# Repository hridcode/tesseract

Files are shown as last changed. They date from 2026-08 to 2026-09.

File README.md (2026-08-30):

# Tesseract

Tesseract is a retro-style MP3 player with audio output to speakers and headphones, an LCD display, and battery charging for on-the-go listening. I made this because I wanted to have a dedicated device to run a library of my favorite music in a simplistic way, as a sort of action against streaming services.

## Features

- 32-bit 48kHz stereo output to speakers and headphones
- microSD card file loading (up to 32GB)
- 2.0" LCD display (ST7789)
- Battery charging with power path
- Album and artist shuffling modes
- Genre tags

## Pictures

|Schematic|PCB|Case|
|---|---|---|
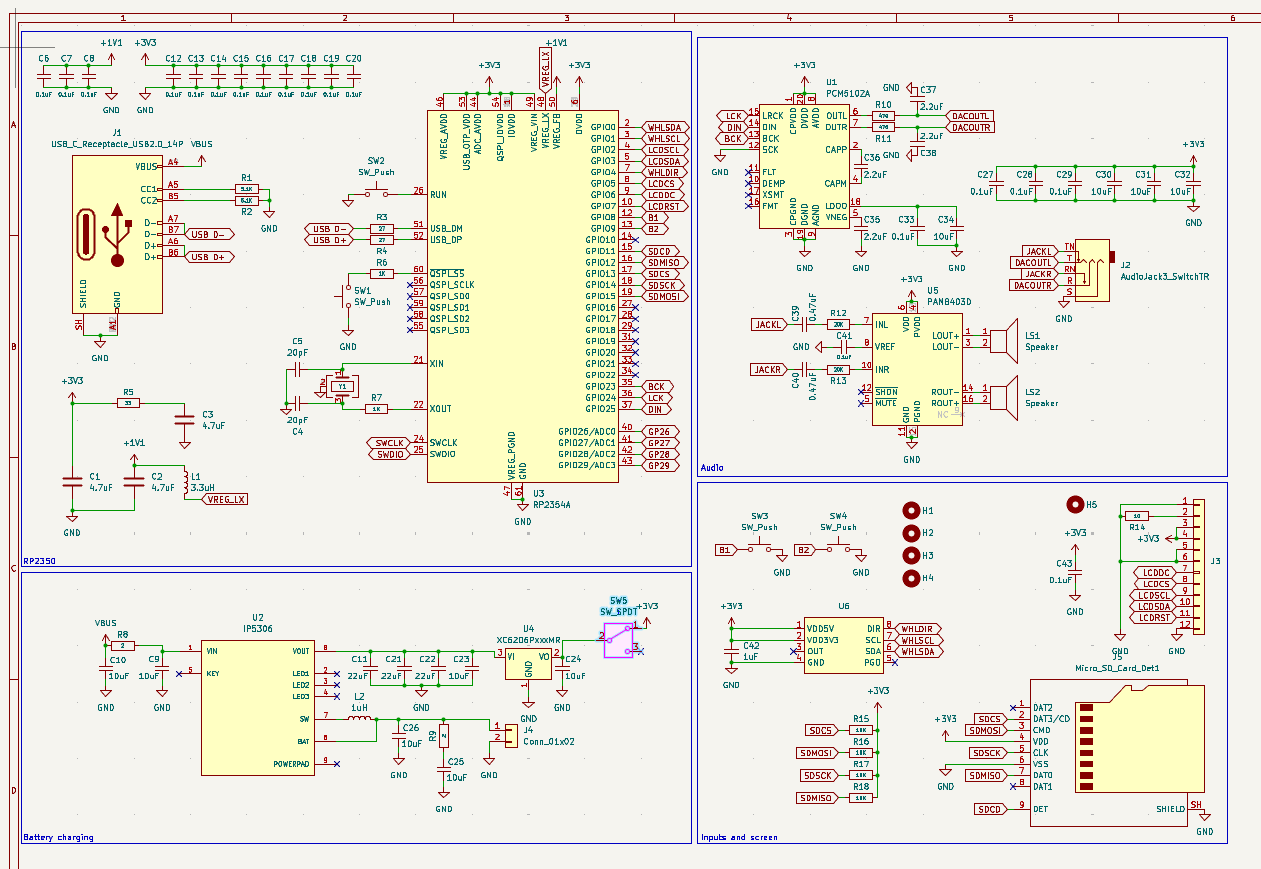
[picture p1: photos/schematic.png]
Schematic
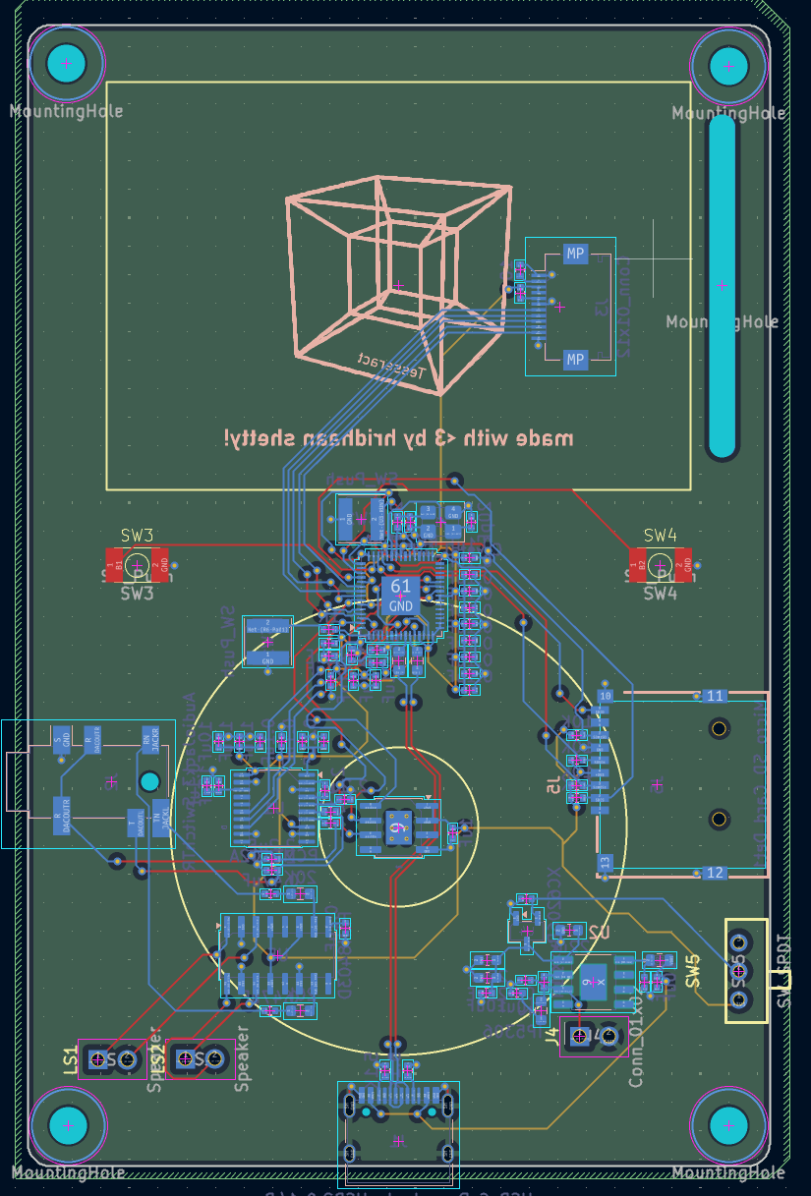
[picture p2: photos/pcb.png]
PCB
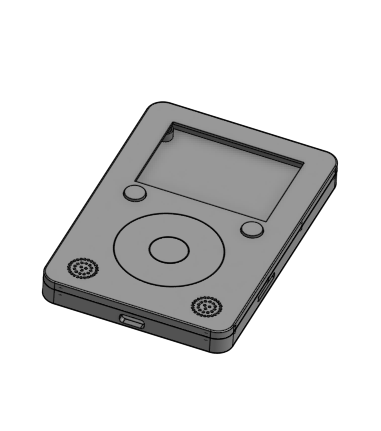
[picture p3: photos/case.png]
Case
||||

## BOM

|Part|Quantity|Cost|Link|
|---|---|---|---|
|0402 4.7uF capacitor|3|$0.070|[LCSC](https://www.lcsc.com/product-detail/C23733.html)|
|0402 10uF capacitor|10|$0.258|[LCSC](https://www.lcsc.com/product-detail/C15525.html)|
|0603 22uF capacitor|3|$0.094|[LCSC](https://www.lcsc.com/product-detail/C59461.html)|
|0402 0.1uF capacitor|18|$0.099|[LCSC](https://www.lcsc.com/product-detail/C1525.html)|
|0402 2.2uF capacitor|4|$0.026|[LCSC](https://www.lcsc.com/product-detail/C12530.html)|
|0402 0.47uF capacitor|2|$0.028|[LCSC](https://www.lcsc.com/product-detail/C47339.html)|
|0402 20pF capacitor|2|$0.016|[LCSC](https://www.lcsc.com/product-detail/C1554.html)|
|0402 1uF capacitor|1|$0.012|[LCSC](https://www.lcsc.com/product-detail/C52923.html)|
|microSD card receptacle|1|$0.061|[LCSC](https://www.lcsc.com/product-detail/C7529389.html)|
|0402 3.3uH inductor|1|$0.076|[LCSC](https://www.lcsc.com/product-detail/C48946153.html)|
|0402 1uH inductor|1|$0.035|[LCSC](https://www.lcsc.com/product-detail/C22400378.html)|
|0402 5.1KΩ resistor|2|$0.005|[LCSC](https://www.lcsc.com/product-detail/C25905.html)|
|0402 470Ω resistor|2|$0.010|[LCSC](https://www.lcsc.com/product-detail/C25117.html)|
|0603 20KΩ resistor|2|$0.008|[LCSC](https://www.lcsc.com/product-detail/C4184.html)|
|0402 10Ω resistor|1|$0.003|[LCSC](https://www.lcsc.com/product-detail/C25077.html)|
|0402 10KΩ resistor|4|$0.019|[LCSC](https://www.lcsc.com/product-detail/C25531.html)|
|0603 27Ω resistor|2|$0.007|[LCSC](https://www.lcsc.com/product-detail/C25190.html)|
|0402 33Ω resistor|1|$0.008|[LCSC](https://www.lcsc.com/product-detail/C25105.html)|
|0402 1KΩ resistor|2|$0.008|[LCSC](https://www.lcsc.com/product-detail/C11702.html)|
|0603 2Ω resistor|2|$0.006|[LCSC](https://www.lcsc.com/product-detail/C22977.html)|
|USB-C receptacle|1|$0.172|[LCSC](https://www.lcsc.com/product-detail/C165948.html)|
|12-pin 0.5mm pitch FPC connector|1|$0.088|[LCSC](https://www.lcsc.com/product-detail/C51901313.html)|
|ST7789 12-pin display|1|$4.060|[AliExpress](https://www.aliexpress.us/item/3256810577766519.html)|
|RP2354A|1|$1.318|[LCSC](https://www.lcsc.com/product-detail/C41378174.html)|
|PCM5102A|1|$1.416|[LCSC](https://www.lcsc.com/product-detail/C107671.html)|
|PAM8403D|1|$0.267|[LCSC](https://www.lcsc.com/product-detail/C5122557.html)|
|PJ-242 switching audio jack|1|$0.138|[LCSC](https://www.lcsc.com/product-detail/C431536.html)|
|8Ω 0.5W 20mm speaker|1|$2.690|[AliExpress](https://www.aliexpress.us/item/3256809939513877.html)|
|IP5306|1|$0.299|[LCSC](https://www.lcsc.com/product-detail/C181692.html)|
|XC6206P332MR|1|$0.147|[LCSC](https://www.lcsc.com/product-detail/C5446.html)|
|3.7V 2000mAh lithium polymer battery|1|$6.990|[AliExpress](https://www.aliexpress.us/item/3256802733222186.html)|
|AS5600-ASOT|1|$1.436|[LCSC](https://www.lcsc.com/product-detail/C499458.html)|
|Diametric magnet|1|$0.199|[AliExpress](https://www.aliexpress.us/item/3256810578708839.html)|
|2x1mm neodymium magnets|50|$3.220|[AliExpress](https://www.aliexpress.us/item/3256811645736463.html)|
|12MHz 20pF crystal oscillator|1|$0.096|[LCSC](https://www.lcsc.com/product-detail/C9002.html)|
|3-pin SPDT slide switch|1|$4.950|[AliExpress](https://www.aliexpress.us/item/3256809632258636.html)|
|PCB|1|$1.400|[JLCPCB](https://cart.jlcpcb.com/quote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)|
|Resin printed parts|5|$8.640|[JLC3DP](https://jlc3dp.com/3d-printing-quote?queryMaterialTechnicsId=1)|
|**Total**||**$40.166**||

## Notes

You can visit the Onshape project [here](https://cad.onshape.com/documents/0cda69ddcaf8f9abaf0bc503/w/b4a9e0f35602d26ad8b0afbe/e/33b76f34621fe33578d60277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).

The PCB is 4 layers (SIG/GND/PWR/SIG).

The firmware is still being developed. I will work on making it better once the device is fully built.

I plan on getting this assembled, hopefully it's not too expensive :(

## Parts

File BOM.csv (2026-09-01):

Part | Quantity | Cost | Link
0402 4.7uF capacitor | 3 | $0.070 | https://www.lcsc.com/product-detail/C23733.html
0402 10uF capacitor | 10 | $0.258 | https://www.lcsc.com/product-detail/C15525.html
0603 22uF capacitor | 3 | $0.094 | https://www.lcsc.com/product-detail/C59461.html
0402 0.1uF capacitor | 18 | $0.099 | https://www.lcsc.com/product-detail/C1525.html
0402 2.2uF capacitor | 4 | $0.026 | https://www.lcsc.com/product-detail/C12530.html
0402 0.47uF capacitor | 2 | $0.028 | https://www.lcsc.com/product-detail/C47339.html
0402 20pF capacitor | 2 | $0.016 | https://www.lcsc.com/product-detail/C1554.html
0402 1uF capacitor | 1 | $0.012 | https://www.lcsc.com/product-detail/C52923.html
microSD card receptacle | 1 | $0.061 | https://www.lcsc.com/product-detail/C7529389.html
0402 3.3uH inductor | 1 | $0.076 | https://www.lcsc.com/product-detail/C48946153.html
0402 1uH inductor | 1 | $0.035 | https://www.lcsc.com/product-detail/C22400378.html
0402 5.1KΩ resistor | 2 | $0.005 | https://www.lcsc.com/product-detail/C25905.html
0402 470Ω resistor | 2 | $0.010 | https://www.lcsc.com/product-detail/C25117.html
0603 20KΩ resistor | 2 | $0.008 | https://www.lcsc.com/product-detail/C4184.html
0402 10Ω resistor | 1 | $0.003 | https://www.lcsc.com/product-detail/C25077.html
0402 10KΩ resistor | 4 | $0.019 | https://www.lcsc.com/product-detail/C25531.html
0603 27Ω resistor | 2 | $0.007 | https://www.lcsc.com/product-detail/C25190.html
0402 33Ω resistor | 1 | $0.008 | https://www.lcsc.com/product-detail/C25105.html
0402 1KΩ resistor | 2 | $0.008 | https://www.lcsc.com/product-detail/C11702.html
0603 2Ω resistor | 2 | $0.006 | https://www.lcsc.com/product-detail/C22977.html
USB-C receptacle | 1 | $0.172 | https://www.lcsc.com/product-detail/C165948.html
12-pin 0.5mm pitch FPC connector | 1 | $0.088 | https://www.lcsc.com/product-detail/C51901313.html
ST7789 12-pin display | 1 | $4.060 | https://www.aliexpress.us/item/3256810577766519.html
RP2354A | 1 | $1.318 | https://www.lcsc.com/product-detail/C41378174.html
PCM5102A | 1 | $1.416 | https://www.lcsc.com/product-detail/C107671.html
PAM8403D | 1 | $0.267 | https://www.lcsc.com/product-detail/C5122557.html
PJ-242 switching audio jack | 1 | $0.138 | https://www.lcsc.com/product-detail/C431536.html
8Ω 0.5W 20mm speaker | 1 | $2.690 | https://www.aliexpress.us/item/3256809939513877.html
IP5306 | 1 | $0.299 | https://www.lcsc.com/product-detail/C181692.html
XC6206P332MR | 1 | $0.147 | https://www.lcsc.com/product-detail/C5446.html
3.7V 2000mAh lithium polymer battery | 1 | $6.990 | https://www.aliexpress.us/item/3256802733222186.html
AS5600-ASOT | 1 | $1.436 | https://www.lcsc.com/product-detail/C499458.html
Diametric magnet | 1 | $0.199 | https://www.aliexpress.us/item/3256810578708839.html
2x1mm neodymium magnets | 50 | $3.220 | https://www.aliexpress.us/item/3256811645736463.html
12MHz 20pF crystal oscillator | 1 | $0.096 | https://www.lcsc.com/product-detail/C9002.html
3-pin SPDT slide switch | 1 | $4.950 | https://www.aliexpress.us/item/3256809632258636.html
PCB | 1 | $1.400 | https://cart.jlcpcb.com/quote?stencilLayer=4&stencilWidth=65&stencilLength=100&stencilCounts=5&plateType=1
Resin printed parts | 5 | $8.640 | https://jlc3dp.com/3d-printing-quote?queryMaterialTechnicsId=1

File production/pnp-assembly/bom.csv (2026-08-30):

Designator | Footprint | Quantity | Value | LCSC Part #
C1, C2, C3 | 0402 | 3 | 4.7uF | C23733
C10, C23, C24, C25, C26, C30, C31, C32, C34, C9 | 0402 | 10 | 10uF | C15525
C11, C21, C22 | 0603 | 3 | 22uF | C59461
C12, C13, C14, C15, C16, C17, C18, C19, C20, C27, C28, C29, C33, C6, C7, C8, C41, C43 | 0402 | 18 | 0.1uF | C1525
C35, C36, C37, C38 | 0402 | 4 | 2.2uF | C12530
C39, C40 | 0402 | 2 | 0.47uF | C47339
C4, C5 | 0402 | 2 | 20pF | C1554
C42 | 0402 | 1 | 1uF | C52923
J1 | USB_C_Receptacle_HRO_TYPE-C-31-M-12 | 1 | USB_C_Receptacle_USB2.0_14P | C165948
J2 | PJ-242 | 1 | AudioJack3_SwitchTR | C431536
J3 | Hirose_FH12-12S-0.5SH_1x12-1MP_P0.50mm_Horizontal | 1 | Conn_01x12 | C51901313
J4 | PinHeader_1x02_P2.54mm_Vertical | 1 | Conn_01x02
J5 | TF-SMD_TF-CARD-H1.8 | 1 | Micro_SD_Card_Det1 | C7529389
L1 | 0402 | 1 | 3.3uH | C84474
L2 | 0402 | 1 | 1uH | C84468
LS1, LS2 | PinHeader_1x02_P2.54mm_Vertical | 2 | Speaker
R1, R2 | 0402 | 2 | 5.1K | C25905
R10, R11 | 0402 | 2 | 470 | C25117
R12, R13 | 0603 | 2 | 20K | C4184
R14 | 0402 | 1 | 10 | C25077
R15, R16, R17, R18 | 0402 | 4 | 10K | C25531
R3, R4 | 0603 | 2 | 27 | C25190
R5 | 0402 | 1 | 33 | C25105
R6, R7 | 0402 | 2 | 1K | C11702
R8, R9 | 0603 | 2 | 2 | C22977
SW1, SW2 | L_Taiyo-Yuden_NR-40xx | 2 | SW_Push
SW3, SW4 | button_342 | 2 | SW_Push
SW5 | SW-TH_MSK12D18G2 | 1 | SW_SPDT
U1 | TSSOP-20_4.4x6.5mm_P0.65mm | 1 | PCM5102A | C107671
U2 | eSOP-8 | 1 | IP5306 | C181692
U3 | QFN-60-1EP_7x7mm_P0.4mm_EP3.4x3.4mm | 1 | RP2354A | C41378174
U4 | SOT-23-3 | 1 | XC6206PxxxMR | C5446
U5 | SOIC-16_3.9x9.9mm_P1.27mm | 1 | PAM8403D | C5122557
U6 | SOIC-8-1EP_3.9x4.9mm_P1.27mm_EP2.29x3mm_ThermalVias | 1 | AS5600 | C499458
Y1 | Crystal_SMD_3225-4Pin_3.2x2.5mm | 1 | Crystal_GND24 | C9002

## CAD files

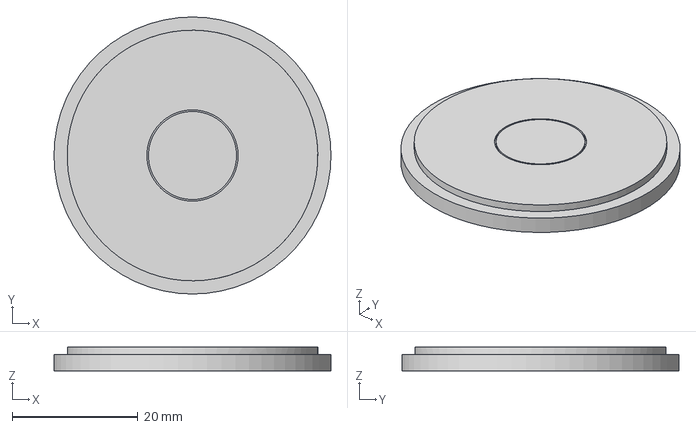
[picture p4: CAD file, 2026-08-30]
production/cad/wheel.step
44.0 x 44.0 x 3.80 mm

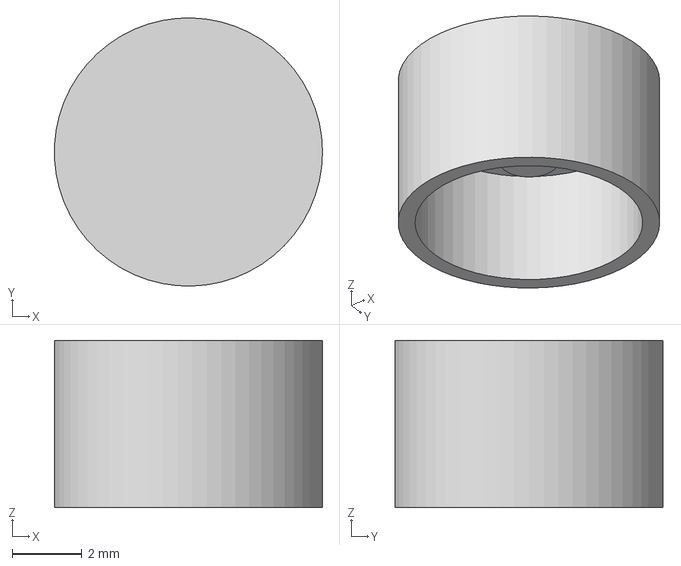
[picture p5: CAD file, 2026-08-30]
production/cad/button 2.step
7.69 x 7.70 x 4.80 mm

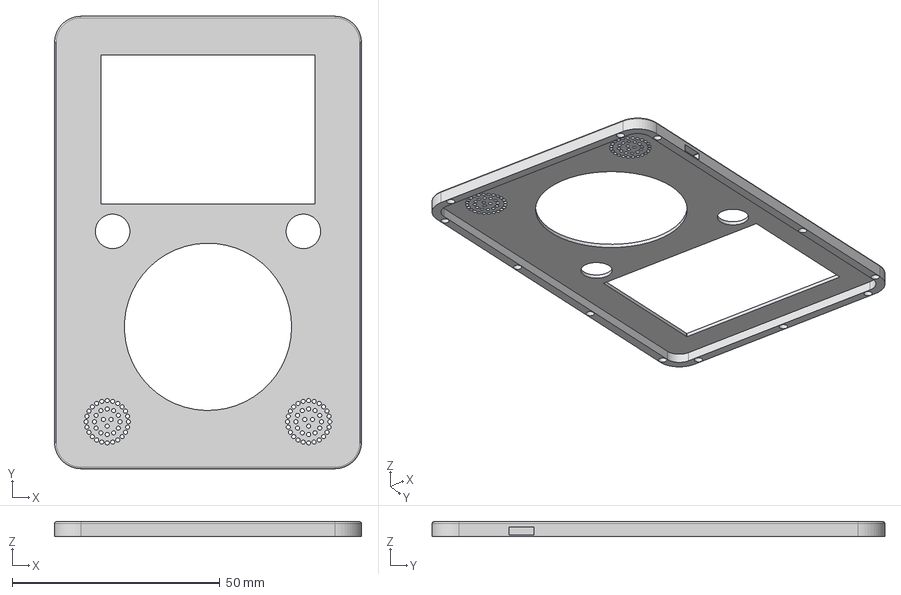
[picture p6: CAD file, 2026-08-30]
production/cad/top case.step
73.8 x 108.8 x 3.50 mm

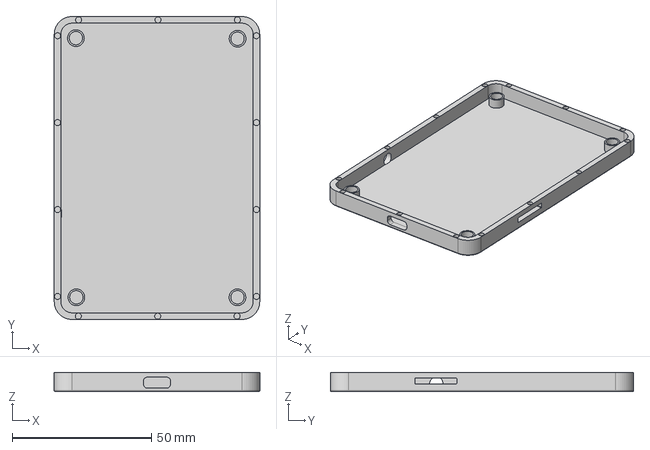
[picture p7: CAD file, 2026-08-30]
production/cad/bottom case.step
73.8 x 108.8 x 7.00 mm

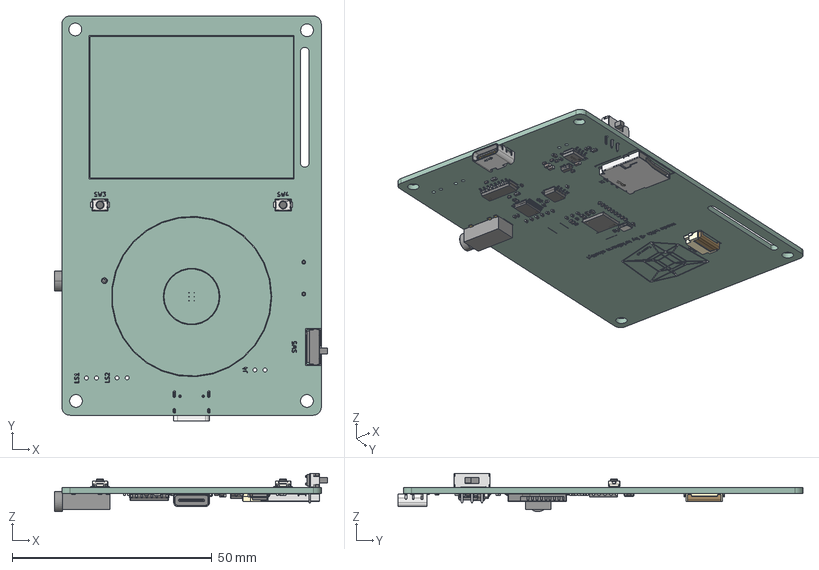
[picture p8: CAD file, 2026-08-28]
production/cad/tesseract.step
68.5 x 101.4 x 9.60 mm
SW-TH_MSK12D18G2
SW-SMD_L3.9-W2.9-H2.0-LS4.8 x 2
AUDIO-SMD_HOOYA_PJ-31060
QFN-60_L7.0-W7.0-P0.40-TL-EP3.4
C_0402_1005Metric x 40
TF-SMD_TF-CARD-H1.8
R_0402_1005Metric x 12
R_0603_1608Metric x 6
Crystal_SMD_3225-4Pin_3.2x2.5mm
lock
pins
SOIC-16_3.9x9.9mm_P1.27mm
L_0402_1005Metric x 2
C_0603_1608Metric x 3
USB-C_SMD-TYPE-C-31-M-12_1
TSSOP-20_4.4x6.5mm_P0.65mm
SOT-23-3
SOIC-8-1EP_3.9x4.9mm_P1.27mm_EP2.29x3mm
ESOP-8_L4.9-W3.9-H1.6-LS6.0-P1.27
tesseract_silkscreen x 2
tesseract_PCB

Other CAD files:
production/cad/button 1.step

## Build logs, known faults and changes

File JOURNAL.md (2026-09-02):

---
title: "Tesseract"
author: "Hridhaan Shetty"
description: "Tesseract is a retro-style MP3 player with 32-bit stereo output to speakers and headphones, an LCD display, and battery charging for on-the-go listening."
created_at: "2026-08-21"
---

# August 22: Finished the schematic

The schematic has been completed. I repurposed an RP2354B devboard design that I had made before, and remodeled it for the RP2354A. I added a stereo speaker amplifier (PAM8403D), the hall effect potentiometer for the wheel (AS5600-ASOM), and an FPC connector for the LCD display (ST7789).

The PAM8403D schematic has a bulk 470uF electrolytic capacitor, but I omitted that because that won't fit into the case. From what I've seen of other amplifier designs, omitting bulk capacitors is fine for small amplification tasks.

There are a LOT of capacitors on this board, since there are so many lines that need to be decoupled (around 40.) Values range from 0.1uF to 22uF.

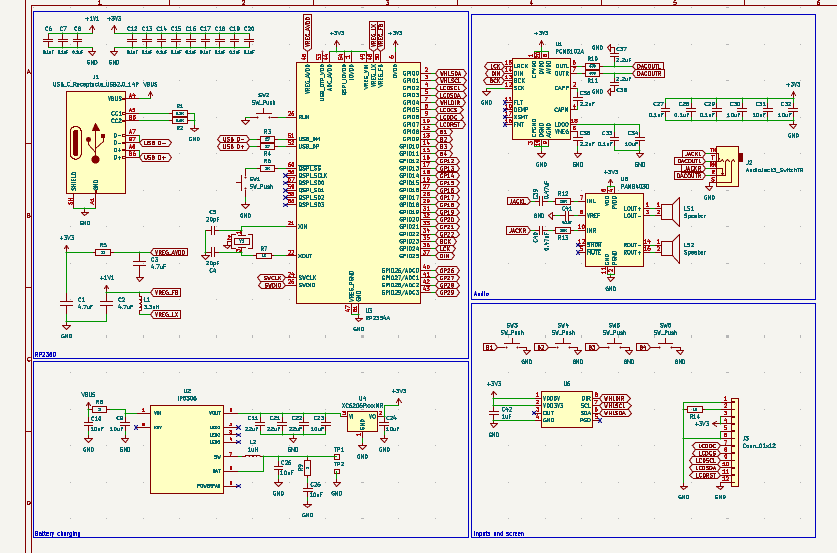
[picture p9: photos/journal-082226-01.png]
Schematic design


Time spent: **1.5 hours**

# August 22: Finished the schematic (again)

I forgot the microSD card slot in the previous journal lmao

Added that in, it's the 9 pin version which means there is a pin for card detection. There are 10KΩ pull-up resistors on the 4 SPI lines.

The card detection pin will be useful for firmware and troubleshooting.

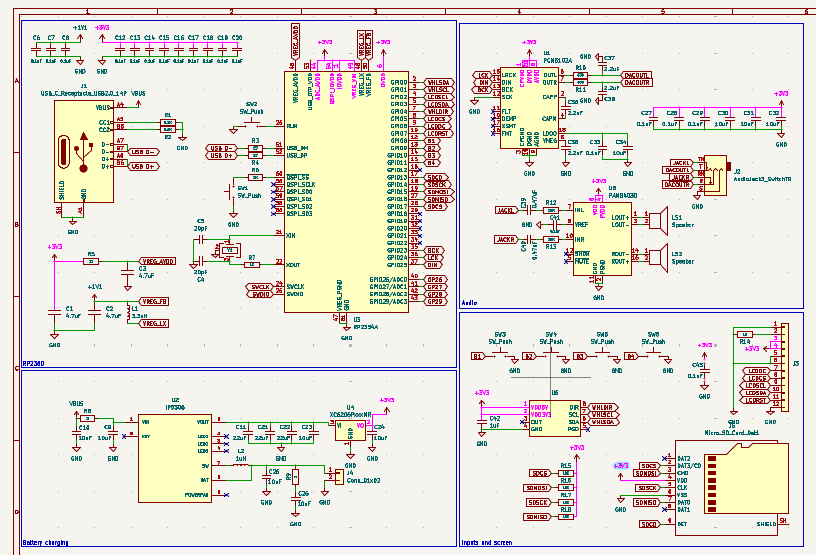
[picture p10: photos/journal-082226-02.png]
Schematic design 2


Time spent: **1 hour**

# August 22: Added footprints for symbols

The footprints were added. This took no time at all, since most of them were already assigned as I copied it from a previous design. I had to import some from easyeda2kicad.py, an open-source Python script that takes LCSC parts and converts them into footprints, since they were not available in KiCad (IP5306, SD card, audio jack).

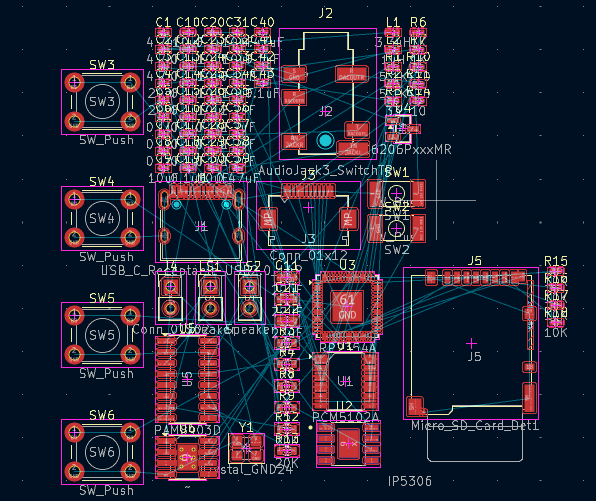
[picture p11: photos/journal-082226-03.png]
Footprints


Time spent: **0.5 hours**

# August 24: Created the PCB layout

The layout is done! The screen at the top has the FPC connector 15mm down, according to the display diagram below. The RP2354A is centered directly in the middle, with its crystal close by, along with their passive components. The battery charging has its own section, as well as the audio, microSD, and USB connector. It is 4 layers, with the first middle layer being a ground plane, and the second middle layer being for power signals (+1V1, +3V3, VBUS). I decided on a 4-layer PCB as I thought the routing would be too dense with only 2 layers. Decoupling capacitors are in close proximity to every single power line.

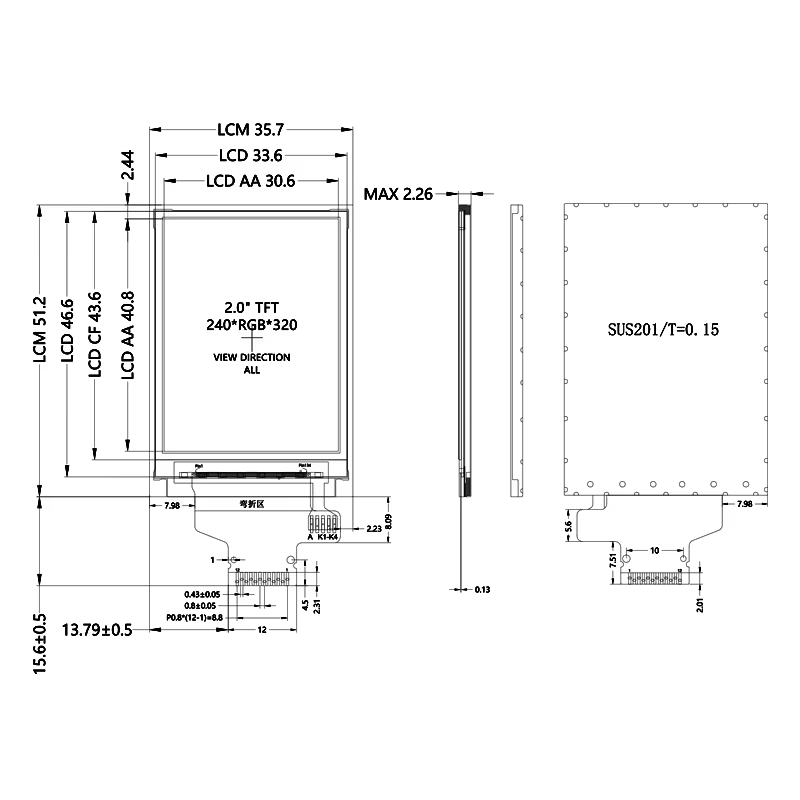
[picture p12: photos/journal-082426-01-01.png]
ST7789 display dimensions

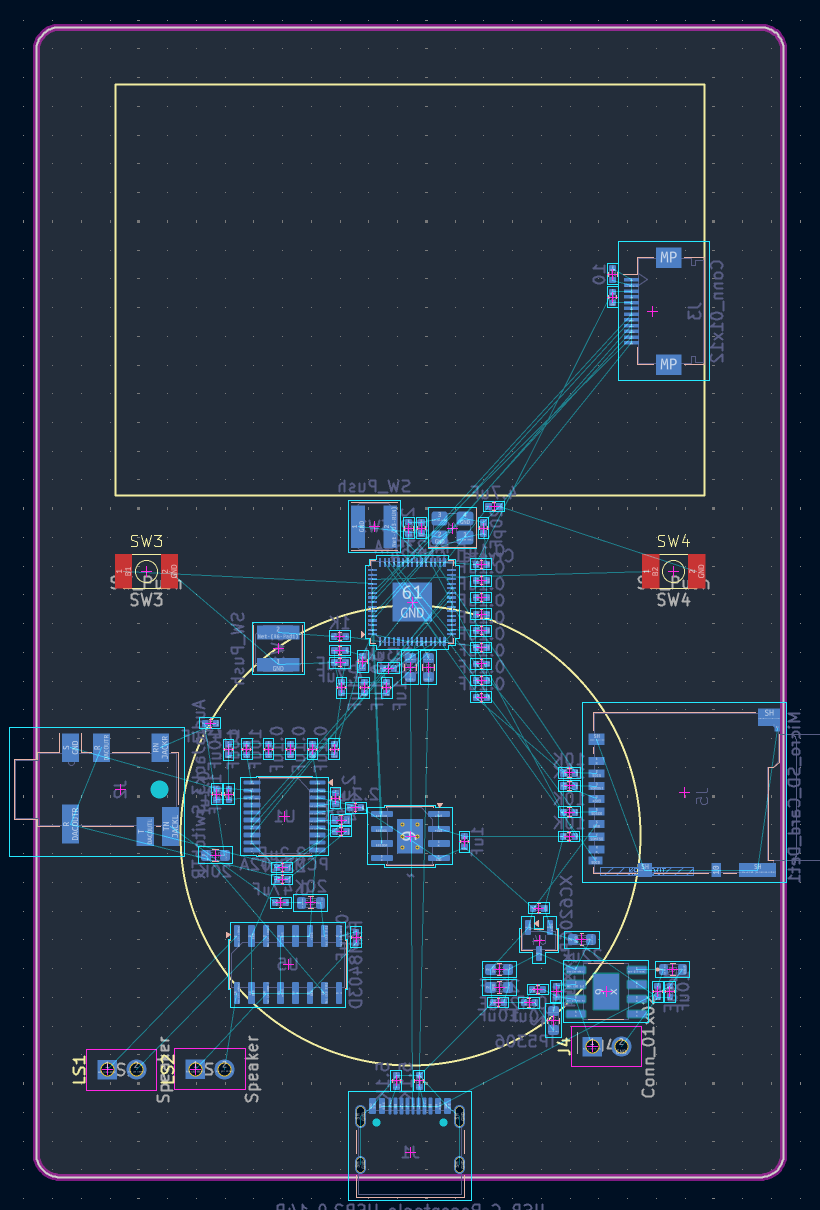
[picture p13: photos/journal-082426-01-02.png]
PCB layout


Time spent: **2 hours**

# August 26: Routed the PCB (Part 1)

The routing on the front and back layers is done. This layer was used for all the signals (wheel, buttons, display, audio) and all the peripherals for the microcontroller (crystal, USB, battery charging).
Next, I have to add vias for ground and power routing, to connect it to the middle layers.

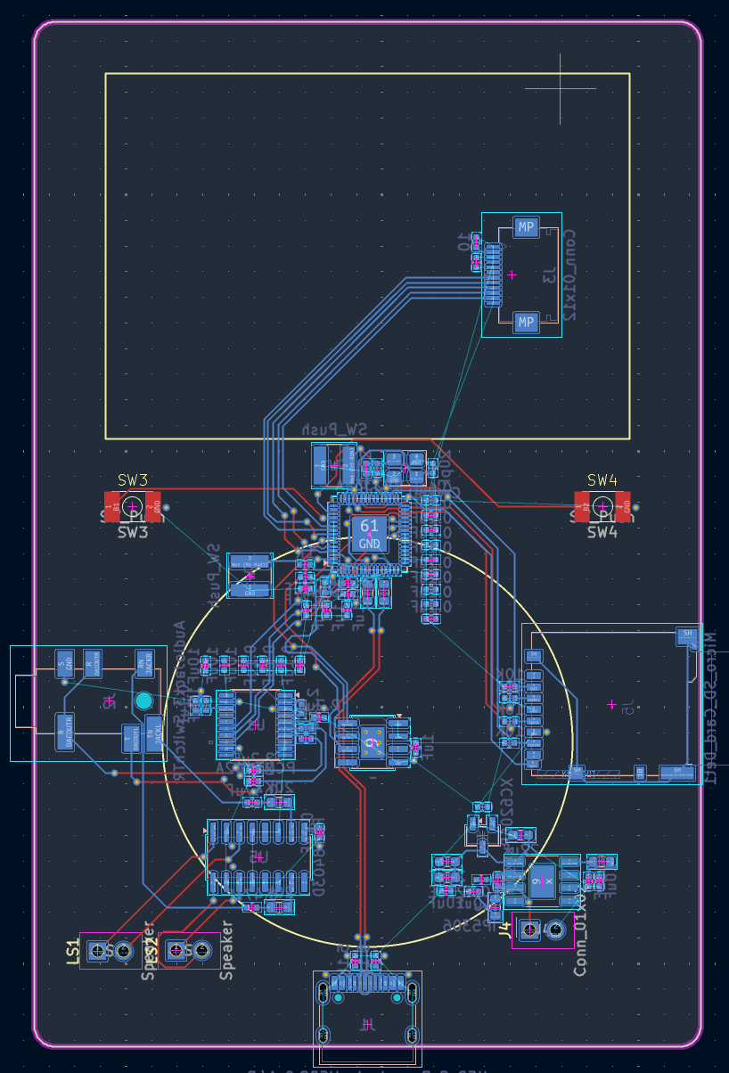
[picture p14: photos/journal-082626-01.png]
PCB signal routing


Time spent: **2 hours**

# August 26: Routed the PCB (Part 2)

The routing is finished! The second layer (green) has a ground plane, while the third layer (orange) is for power signals. Vias are connected from each ground/power pad in order to connect it to the inner layers.
M3 mounting holes are added at the corners, and a big NPTH hole is added near the display to fit the FPC connector of the display through to the other side. 
The SD card footprint was changed to fit one from LCSC.

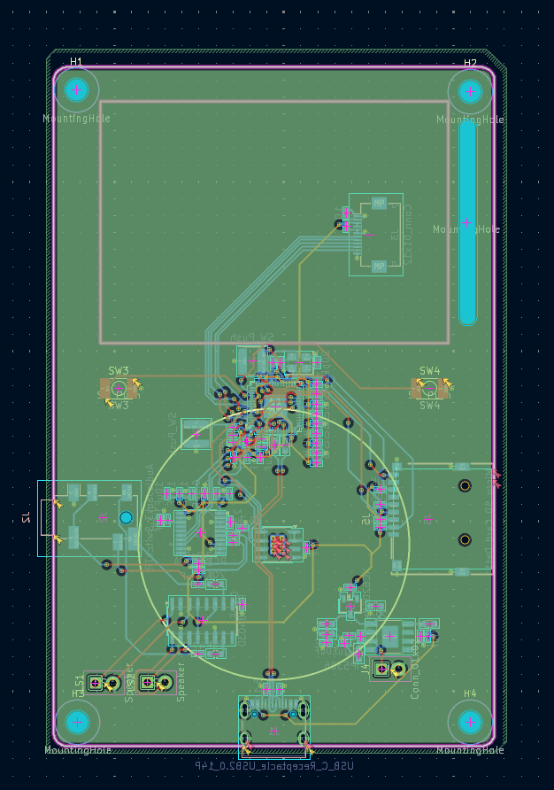
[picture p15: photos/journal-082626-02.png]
PCB routing finished


Time spent: **2 hours**

# August 27: Modeled the case (Part 1)

The case is basically halfway done. The geometry for the bottom and top cases is finished, as well as the mounting holes for the PCB to screw into, the display cutout, the wheel, and the magnet holes to connect the top and bottom cases. 
I decided on magnets to mount the two halves together, as there is no space for screws.

I really only need to add cutouts for ports and speaker grills, and anything else I see fit.

I learned to use Onshape for this project, but it was quite similar to Fusion 360 since both are CAD-based softwares. I learned about contexts, assemblies, and part studios. I think I prefer it to F360. (and it's free too!)

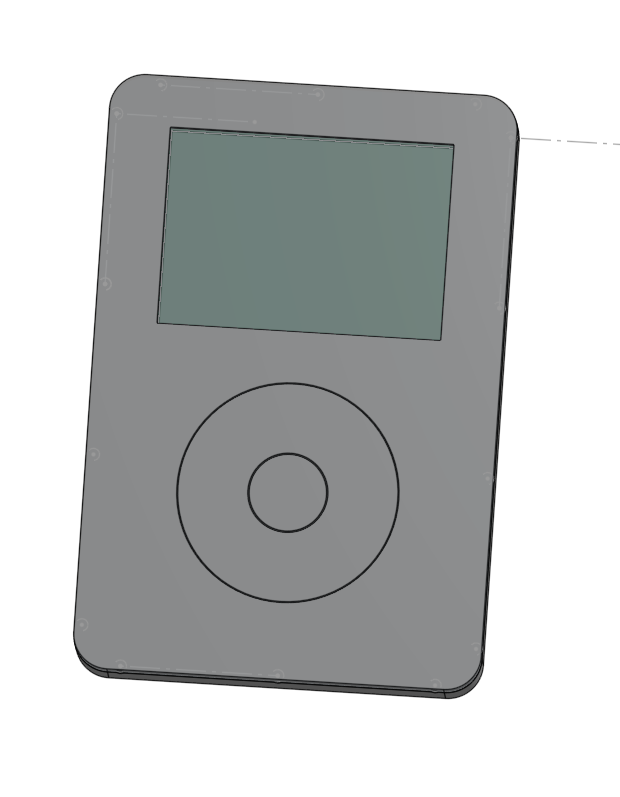
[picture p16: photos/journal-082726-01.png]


Time spent: **3 hours**

# August 27: Modeled the case (Part 2)

The case is done! The speaker grills, port cutouts, and button caps are modeled, with 0.4-0.7mm tolerances. 

The buttons stick out a little bit, so that you can press it easily.
For the speaker grills, I used a circular pattern for easier symmetry.
The port cutouts have around a 0.5mm offset each, and I needed one for the audio jack, USB-C port and microSD card slot.

It looks kind of ugly, but oh well.

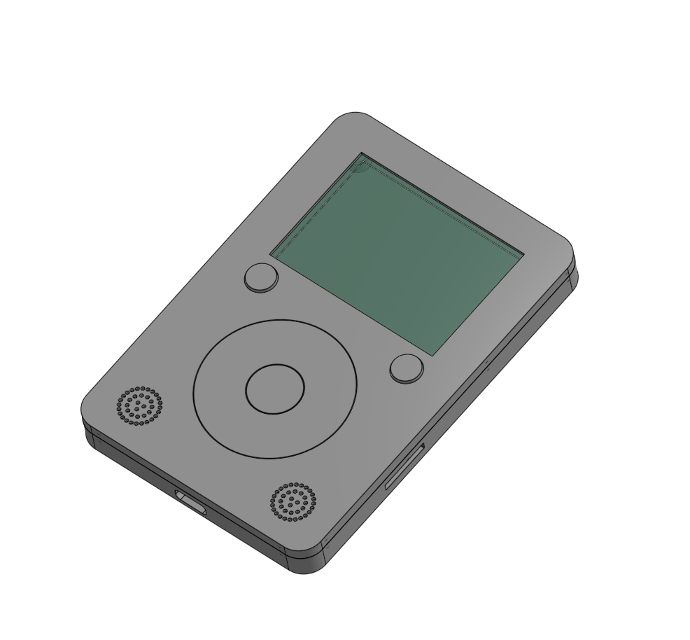
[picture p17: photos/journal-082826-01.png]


Time spent: **1 hour**

# August 28: Created firmware

I created a very simple firmware in MicroPython for the device. This initializes the peripherals, reads a file "metadata.json" from the SD card, and plays the songs in order, displaying the covers, artists, and respective albums. Once I actually build the thing, I'll rewrite the firmware.

The libraries I needed were the ST7789, AS5600, and SD card libraries.

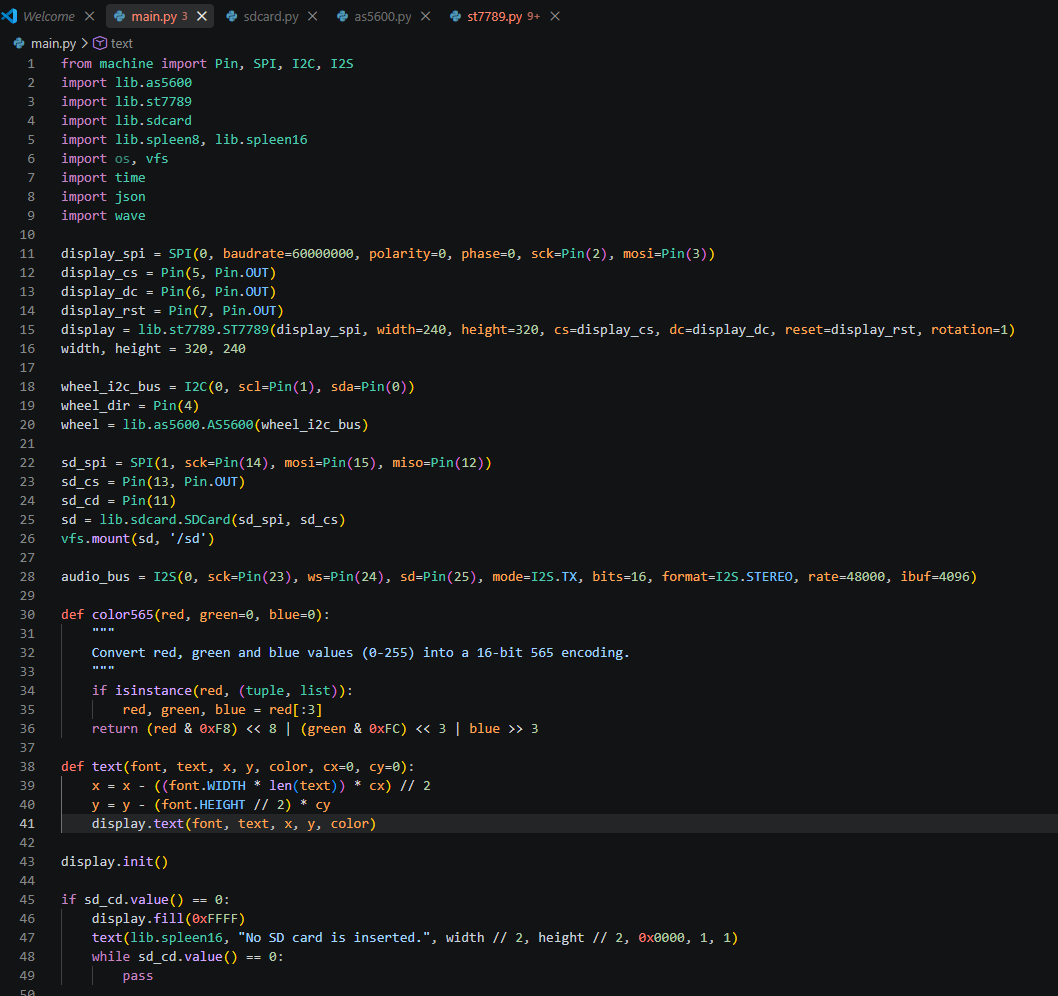
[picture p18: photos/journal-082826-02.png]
Firmware snippet


Time spent: **1.5 hours**

# August 28: Added slide switch

Since I realized I had no way to turn the device on/off, I added a right-angled slide switch. This required updating the schematic, PCB, and case. There is a hole cutout in the case, and the switch is through-hole. It hopefully will be easy to push on and off.

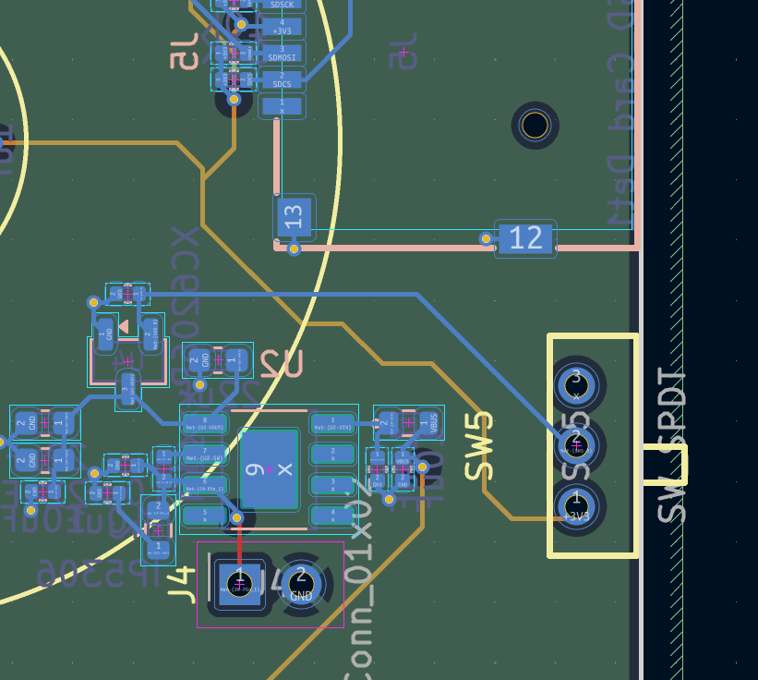
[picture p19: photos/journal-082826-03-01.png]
Updated PCB

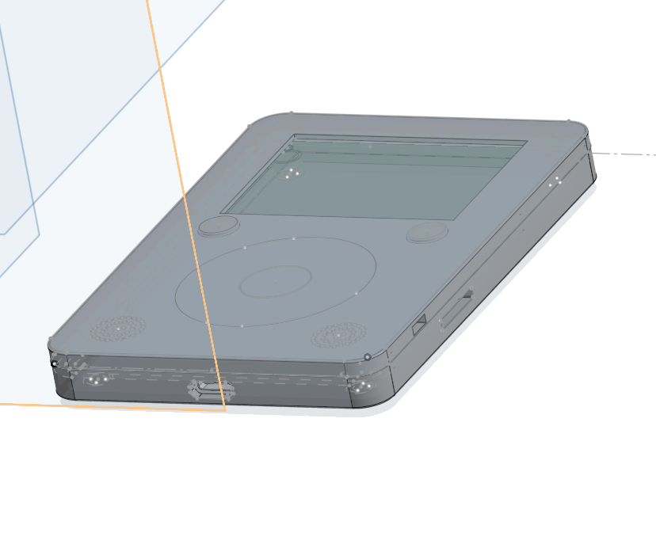
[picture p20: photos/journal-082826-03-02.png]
Updated case


Time spent: **1 hour**

# August 29: Added BOM

I added the BOM today and got the files ready for production. This took a long time since I had to match up every part and find its data, but I used a custom Python script to generate the markdown table. I also got the AliExpress parts into the BOM.

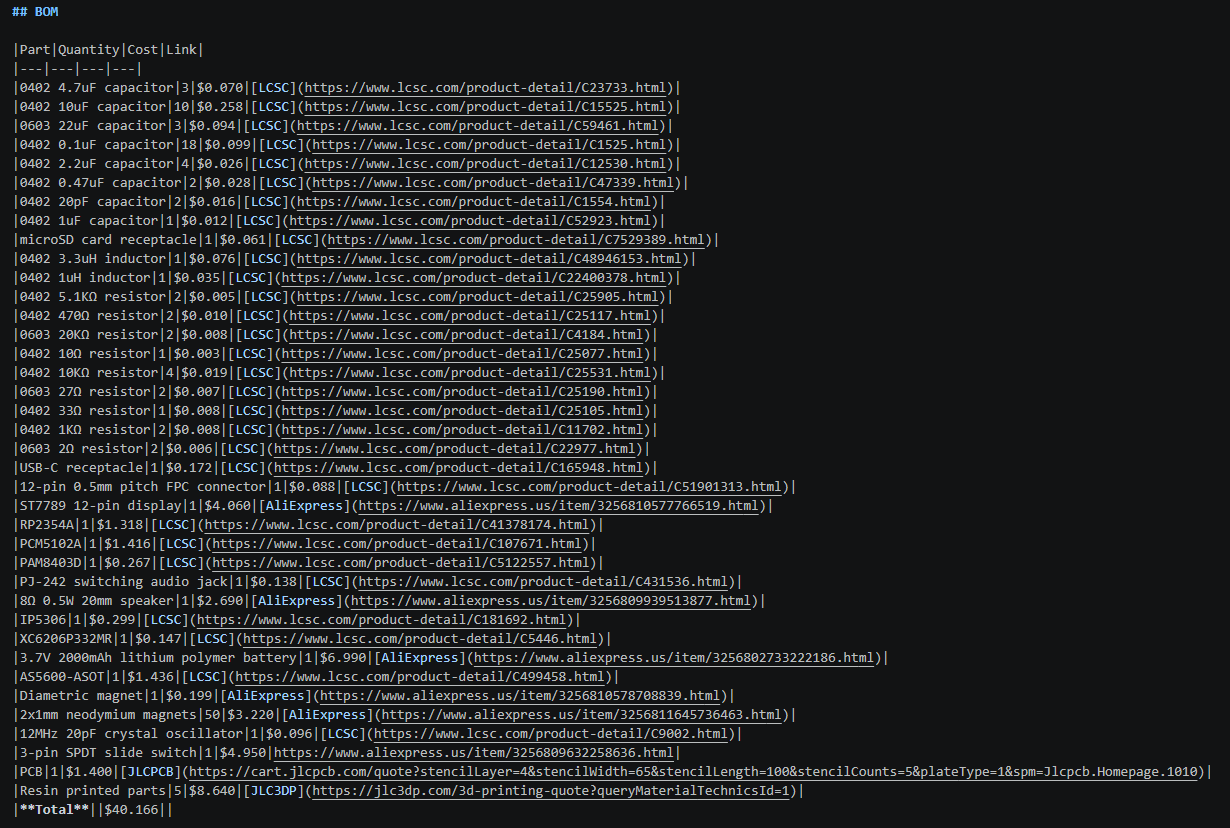
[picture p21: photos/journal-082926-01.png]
BOM


Time spent: **3 hours**

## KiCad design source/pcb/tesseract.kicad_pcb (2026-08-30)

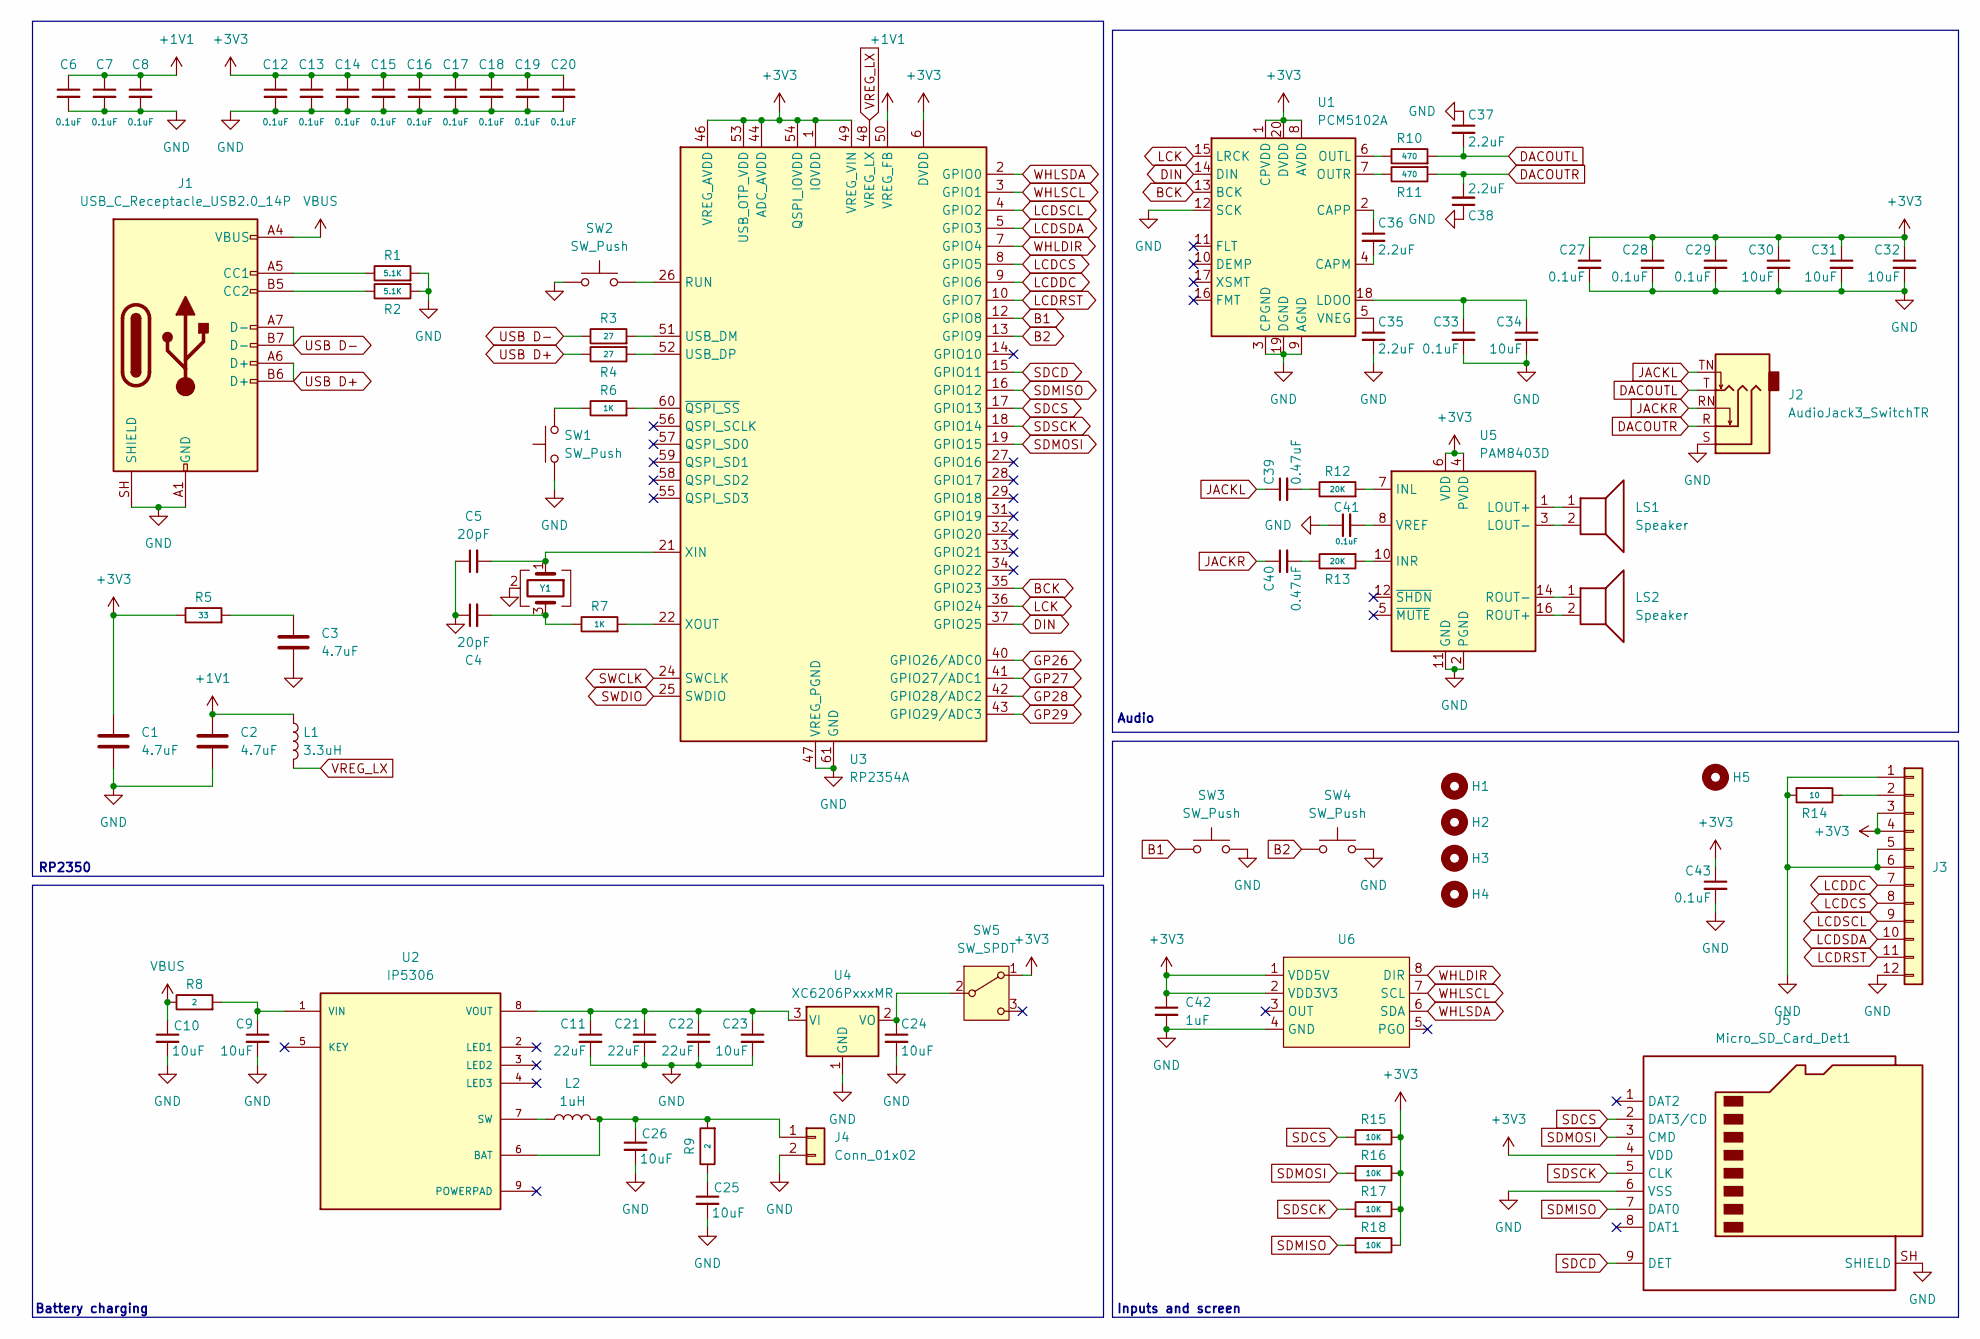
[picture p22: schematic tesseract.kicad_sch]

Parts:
C1, C2, C3: 4.7uF; C_0402_1005Metric; MPN C23733
C4, C5: 20pF; C_0402_1005Metric; MPN C1554
C6, C7, C8, C12, C13, C14, C15, C16, C17, C18, C19, C20, C27, C28, C29, C33: 0.1uF; C_0402_1005Metric; MPN C1525
C9, C10, C23, C24, C25, C26, C30, C31, C32, C34: 10uF; C_0402_1005Metric; MPN C15525
C11, C21, C22: 22uF; C_0603_1608Metric; MPN C59461
C35, C36, C37, C38: 2.2uF; C_0402_1005Metric; MPN C12530
C39, C40: 0.47uF; C_0402_1005Metric; MPN C1525
C41: 0.1uF; C_0402_1005Metric
C42: 1uF; C_0402_1005Metric
C43: 0.1uF; C_0402_1005Metric; MPN C15525
H1, H2, H3, H4: MountingHole; MountingHole_3.2mm_M3
H5: MountingHole; display_hole
J1: USB_C_Receptacle_USB2.0_14P; USB_C_Receptacle_HRO_TYPE-C-31-M-12; MPN C165948
J2: AudioJack3_SwitchTR; AUDIO-SMD_PJ-242_1
J3: Conn_01x12; Hirose_FH12-12S-0.5SH_1x12-1MP_P0.50mm_Horizontal
J4: Conn_01x02; PinHeader_1x02_P2.54mm_Vertical
J5: Micro_SD_Card_Det1; TF-SMD_TF-CARD-H1.8
L1: 3.3uH; L_0402_1005Metric; MPN C84474
L2: 1uH; L_0402_1005Metric; MPN C84468
LS1, LS2: Speaker; PinHeader_1x02_P2.54mm_Vertical
R1, R2: 5.1K; R_0402_1005Metric; MPN C25905
R3, R4: 27; R_0603_1608Metric; MPN C25190
R5: 33; R_0402_1005Metric; MPN C25105
R6, R7: 1K; R_0402_1005Metric; MPN C11702
R8, R9: 2; R_0603_1608Metric; MPN C22977
R10, R11: 470; R_0402_1005Metric; MPN C25117
R12, R13: 20K; R_0603_1608Metric; MPN C25190
R14: 10; R_0402_1005Metric; MPN C11702
R15, R16, R17, R18: 10K; R_0402_1005Metric; MPN C11702
SW1, SW2: SW_Push; L_Taiyo-Yuden_NR-40xx
SW3, SW4: SW_Push; button_342
SW5: SW_SPDT; SW-TH_MSK12D18G2
U1: PCM5102A; TSSOP-20_4.4x6.5mm_P0.65mm; MPN C107671
U2: IP5306; eSOP-8; PARTREV 1.31
U3: RP2354A; QFN-60-1EP_7x7mm_P0.4mm_EP3.4x3.4mm
U4: XC6206PxxxMR; SOT-23-3; MPN C5446
U5: PAM8403D; SOIC-16_3.9x9.9mm_P1.27mm
U6: SOIC-8-1EP_3.9x4.9mm_P1.27mm_EP2.29x3mm_ThermalVias
Y1: Crystal_GND24; Crystal_SMD_3225-4Pin_3.2x2.5mm; MPN C9002

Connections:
+1V1: C2.1, C6.1, C7.1, C8.1, L1.1, U3.50 (VREG_FB)
+3V3: C1.1, C12.1, C13.1, C14.1, C15.1, C16.1, C17.1, C18.1, C19.1, C20.1, C27.1, C28.1, C29.1, C30.1, C31.1, C32.1, C42.1, C43.1, J3.3, J3.4, J5.4 (VDD), R5.1, R15.1, R16.1, R17.1, R18.1, SW5.1 (A), U1.1 (CPVDD), U1.8 (AVDD), U1.20 (DVDD), U3.1 (IOVDD), U3.6 (DVDD), U3.11 (IOVDD), U3.20 (IOVDD), U3.23 (DVDD), U3.30 (IOVDD), U3.38 (IOVDD), U3.39 (DVDD), U3.44 (ADC_AVDD), U3.45 (IOVDD), U3.46 (VREG_AVDD), U3.49 (VREG_VIN), U3.53 (USB_OTP_VDD), U3.54 (QSPI_IOVDD), U5.4 (PVDD), U5.6 (VDD), U5.13 (PVDD), U6.1 (VDD5V), U6.2 (VDD3V3)
B1: SW3.1, U3.12 (GPIO8)
B2: SW4.1, U3.13 (GPIO9)
BCK: U1.13 (BCK), U3.35 (GPIO23)
DACOUTL: C37.2, J2.T, R10.2
DACOUTR: C38.2, J2.R, R11.2
DIN: U1.14 (DIN), U3.37 (GPIO25)
GND: C1.2, C2.2, C3.2, C4.1, C5.1, C6.2, C7.2, C8.2, C9.2, C10.2, C11.2, C12.2, C13.2, C14.2, C15.2, C16.2, C17.2, C18.2, C19.2, C20.2, C21.2, C22.2, C23.2, C24.2, C25.2, C26.2, C27.2, C28.2, C29.2, C30.2, C31.2, C32.2, C33.2, C34.2, C35.2, C37.1, C38.1, C41.1, C42.2, C43.2, J1.A1 (GND), J1.A12 (GND), J1.B1 (GND), J1.B12 (GND), J1.SH (SHIELD), J2.S, J3.1, J3.5, J3.6, J3.12, J4.2, J5.6 (VSS), J5.SH (SHIELD), R1.2, R2.2, R14.2, SW1.1, SW2.1, SW3.2, SW4.2, U1.3 (CPGND), U1.9 (AGND), U1.12 (SCK), U1.19 (DGND), U3.47 (VREG_PGND), U3.61 (GND), U4.1 (GND), U5.2 (PGND), U5.11 (GND), U5.15 (PGND), U6.4 (GND), Y1.2 (G), Y1.4 (G)
GP26: U3.40 (GPIO26/ADC0)
GP27: U3.41 (GPIO27/ADC1)
GP28: U3.42 (GPIO28/ADC2)
GP29: U3.43 (GPIO29/ADC3)
JACKL: C39.1, J2.TN
JACKR: C40.1, J2.RN
LCDCS: J3.8, U3.8 (GPIO5)
LCDDC: J3.7, U3.9 (GPIO6)
LCDRST: J3.11, U3.10 (GPIO7)
LCDSCL: J3.9, U3.4 (GPIO2)
LCDSDA: J3.10, U3.5 (GPIO3)
LCK: U1.15 (LRCK), U3.36 (GPIO24)
unnamed: C3.1, R5.2
unnamed: C4.2, R7.1, Y1.3
unnamed: C25.1, R9.1
unnamed: C39.2, R12.1
unnamed: C40.2, R13.1
unnamed: J1.A5 (CC1), R1.1
unnamed: J1.B5 (CC2), R2.1
unnamed: J3.2, R14.1
unnamed: C26.1, J4.1, L2.2, R9.2, U2.6 (BAT)
unnamed: R6.1, SW1.2
unnamed: C24.1, SW5.2 (B), U4.2 (VO)
unnamed: C36.2, U1.4 (CAPM)
unnamed: C36.1, U1.2 (CAPP)
unnamed: C33.1, C34.1, U1.18 (LDOO)
unnamed: R10.1, U1.6 (OUTL)
unnamed: R11.1, U1.7 (OUTR)
unnamed: C35.1, U1.5 (VNEG)
unnamed: L2.1, U2.7 (SW)
unnamed: C9.1, R8.2, U2.1 (VIN)
unnamed: C11.1, C21.1, C22.1, C23.1, U2.8 (VOUT), U4.3 (VI)
unnamed: SW2.2, U3.26 (RUN)
unnamed: R3.2, U3.51 (USB_DM)
unnamed: R4.2, U3.52 (USB_DP)
unnamed: C5.2, U3.21 (XIN), Y1.1
unnamed: R7.2, U3.22 (XOUT)
unnamed: R6.2, U3.60 (~QSPI_SS)
unnamed: R12.2, U5.7 (INL)
unnamed: R13.2, U5.10 (INR)
unnamed: LS1.1, U5.1 (LOUT+)
unnamed: LS1.2, U5.3 (LOUT-)
unnamed: LS2.2, U5.16 (ROUT+)
unnamed: LS2.1, U5.14 (ROUT-)
unnamed: C41.2, U5.8 (VREF)
SDCD: J5.9 (DET), U3.15 (GPIO11)
SDCS: J5.2 (DAT3/CD), R15.2, U3.17 (GPIO13)
SDMISO: J5.7 (DAT0), R18.2, U3.16 (GPIO12)
SDMOSI: J5.3 (CMD), R16.2, U3.19 (GPIO15)
SDSCK: J5.5 (CLK), R17.2, U3.18 (GPIO14)
SWCLK: U3.24 (SWCLK)
SWDIO: U3.25 (SWDIO)
USB D+: J1.A6 (D+), J1.B6 (D+), R4.1
USB D-: J1.A7 (D-), J1.B7 (D-), R3.1
VBUS: C10.1, J1.A4 (VBUS), J1.A9 (VBUS), J1.B4 (VBUS), J1.B9 (VBUS), R8.1
VREG_LX: L1.2, U3.48 (VREG_LX)
WHLDIR: U3.7 (GPIO4), U6.8 (DIR)
WHLSCL: U3.3 (GPIO1), U6.7 (SCL)
WHLSDA: U3.2 (GPIO0), U6.6 (SDA)

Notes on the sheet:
Audio
Battery charging
Inputs and screen
RP2350

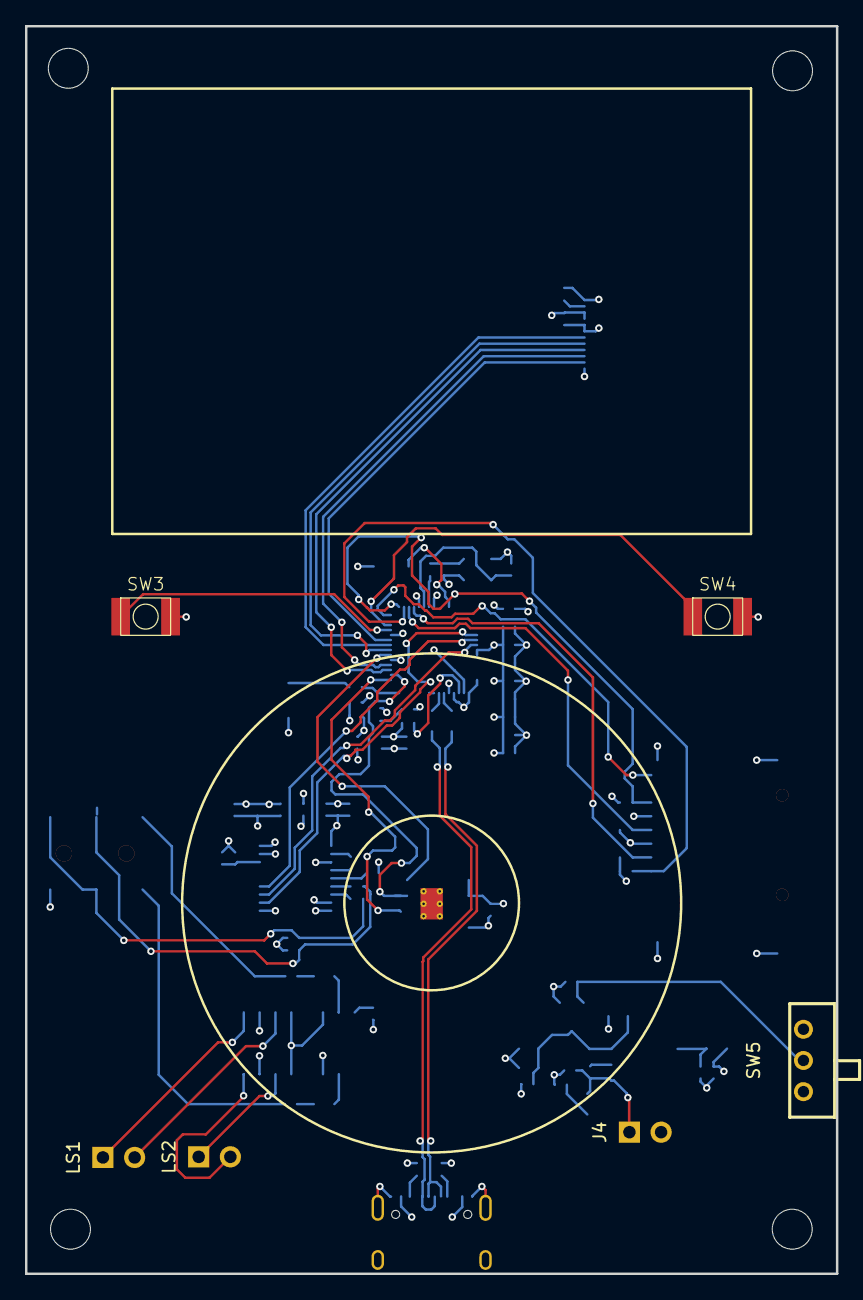
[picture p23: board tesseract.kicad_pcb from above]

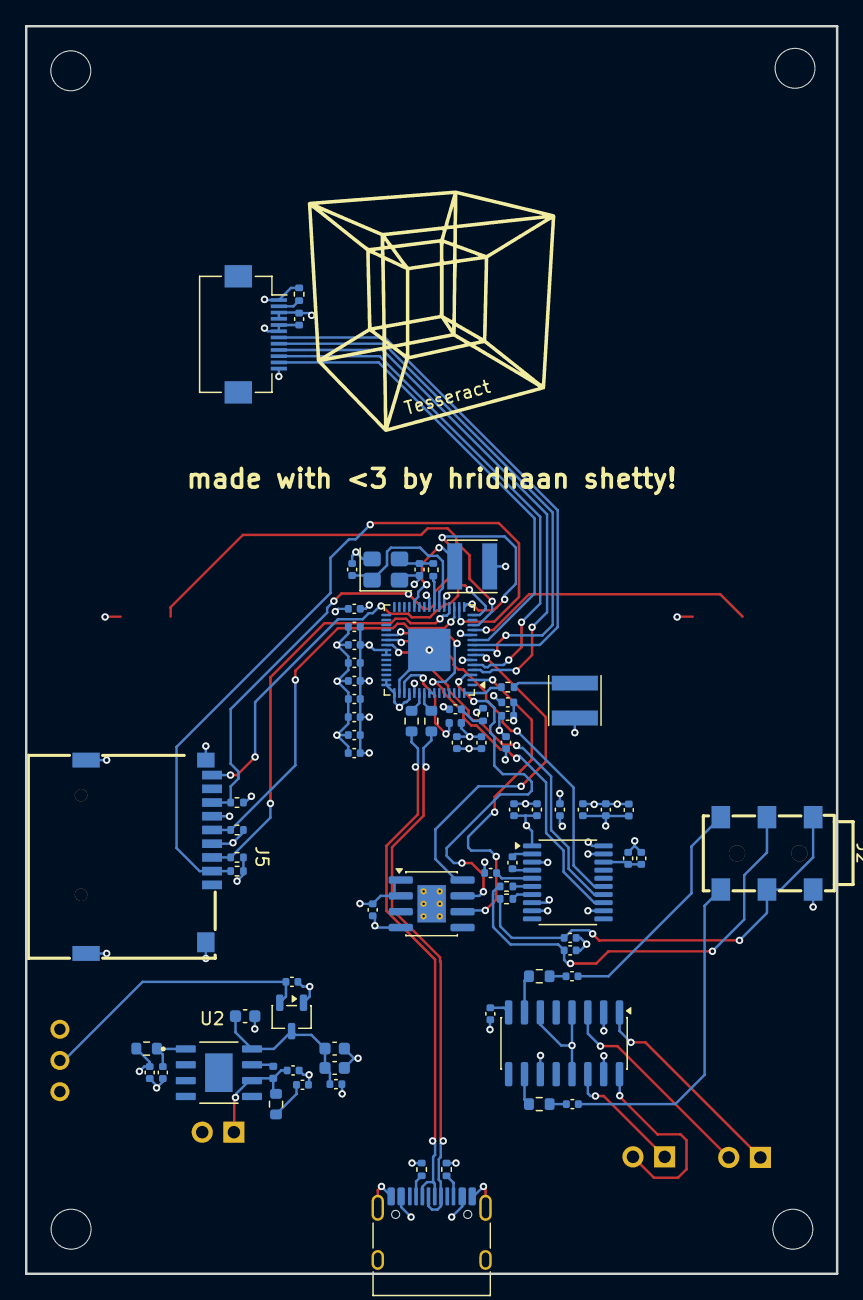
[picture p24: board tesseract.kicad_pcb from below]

Board: 4 copper layers, 65.0 x 100.0 mm, 87 parts (76 on the bottom side), 62 nets.

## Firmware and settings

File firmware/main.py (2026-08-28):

from machine import Pin, SPI, I2C, I2S
import lib.as5600
import lib.st7789
import lib.sdcard
import lib.spleen8, lib.spleen16
import os, vfs
import time
import json
import wave

display_spi = SPI(0, baudrate=60000000, polarity=0, phase=0, sck=Pin(2), mosi=Pin(3))
display_cs = Pin(5, Pin.OUT)
display_dc = Pin(6, Pin.OUT)
display_rst = Pin(7, Pin.OUT)
display = lib.st7789.ST7789(display_spi, width=240, height=320, cs=display_cs, dc=display_dc, reset=display_rst, rotation=1)
width, height = 320, 240

wheel_i2c_bus = I2C(0, scl=Pin(1), sda=Pin(0))
wheel_dir = Pin(4)
wheel = lib.as5600.AS5600(wheel_i2c_bus)

sd_spi = SPI(1, sck=Pin(14), mosi=Pin(15), miso=Pin(12))
sd_cs = Pin(13, Pin.OUT)
sd_cd = Pin(11)
sd = lib.sdcard.SDCard(sd_spi, sd_cs)
vfs.mount(sd, '/sd')

audio_bus = I2S(0, sck=Pin(23), ws=Pin(24), sd=Pin(25), mode=I2S.TX, bits=16, format=I2S.STEREO, rate=48000, ibuf=4096)

def color565(red, green=0, blue=0):
    """
    Convert red, green and blue values (0-255) into a 16-bit 565 encoding.
    """
    if isinstance(red, (tuple, list)):
        red, green, blue = red[:3]
    return (red & 0xF8) << 8 | (green & 0xFC) << 3 | blue >> 3

def text(font, text, x, y, color, cx=0, cy=0):
    x = x - ((font.WIDTH * len(text)) * cx) // 2
    y = y - (font.HEIGHT // 2) * cy
    display.text(font, text, x, y, color)

display.init()

if sd_cd.value() == 0:
    display.fill(0xFFFF)
    text(lib.spleen16, "No SD card is inserted.", width // 2, height // 2, 0x0000, 1, 1)
    while sd_cd.value() == 0:
        pass

display.fill(0xFFFF)
text(lib.spleen16, "Reading metadata.json...", width // 2, height // 2, 0x0000, 1, 1)

try:
    with open("/sd/metadata.json", "r") as f:
        metadata = json.load(f)
except Exception as e:
    display.fill(0xFFFF)
    text(lib.spleen16, "Error occured. Restart your device.", width // 2, height // 2, 0x0000, 1, 1)

# metadata = [
#     {
#         'name': 'Mural',
#         'artists': ['Lupe Fiasco'],
#         'album': 'Tetsuo & Youth',
#         'cover': 'cover001.png',
#         'file': 'file001.wav'
#     }
# ]

display.fill(0xFFFF)
text(lib.spleen16, f"Found {len(metadata)} songs", width // 2, height // 2, 0x0000, 1, 1)

time.sleep(1)

wave_current_file = -1
wave_current_object = None
wave_current_frame = 0
wave_current_cover = None
wave_current_length = 0
playing = False

def format_time(seconds):
    m, s = divmod(seconds, 60)
    m, s = int(m), int(s)
    return f"{m}:{s:03}"

def cut_string(text, length, char_length):
    if len(text) > length // char_length:
        return text[:length//char_length-3] + '...'
    return text

def cue(song):
    global playing, wave_current_object, wave_current_file, wave_current_frame, wave_current_cover, wave_current_length
    playing = False

    wave_current_file = song
    wave_current_frame = 0
    wave_current_object = wave.open(metadata[song]["file"])
    with open(metadata[song]["cover"], "rb") as f:
        wave_current_cover = bytearray(f.read())

    wave_current_length = wave_current_object.getnframes() // wave_current_object.getframerate()

    playing = True

while True:
    written = None
    if playing:
        frames = wave_current_object.getnframes(512)
        if wave_current_object.getnchannels() == 1:
            buf = bytearray([0 for _ in range(1024)])
            buf[0::2] = frames
            buf[1::2] = frames
            frames = buf

        written = audio_bus.write(frames)

        display.fill(0xFFFF)
        display.blit_buffer(wave_current_cover, 30, 30, 100, 100)

        text(lib.spleen16, cut_string(metadata[wave_current_file]["name"], 160, 16), 138, 30, 0x0000)
        text(lib.spleen8, cut_string(", ".join(metadata[wave_current_file]["artists"]), 160, 16), 138, 60, 0x0000)
        text(lib.spleen8, cut_string(metadata[wave_current_file]["album"], 160, 16), 138, 70, 0x0000)

        while len(written) < 1024:
            pass

        wave_current_frame += 512 
        

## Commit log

2026-08-22 Added first journal entry
    [tesseract.kicad_pcb, tesseract.kicad_sch]
2026-08-22 Added microSD card to schematic
    [tesseract.kicad_pcb, tesseract.kicad_sch]
2026-08-22 Assigned footprints to symbols
    [tesseract.kicad_pcb, tesseract.kicad_sch]
2026-08-24 Created PCB layout
    [tesseract.kicad_pcb, tesseract.kicad_sch]
2026-08-26 Routed PCB signals
    [tesseract.kicad_pcb]
2026-08-26 Finished PCB routing
    [tesseract.kicad_pcb, tesseract.kicad_sch]
2026-08-26 Added missing hours
    [tesseract.kicad_pcb, tesseract.step]
2026-08-27 Created first prototype of case
    [tesseract.kicad_pcb]
2026-08-28 Finished case
2026-08-28 Added slide switch and created firmware
    [tesseract.kicad_pcb, tesseract.kicad_sch, tesseract.step]
2026-08-30 Added BOM
    [bom.csv, bottom case.step, button 1.step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]
2026-09-01 Updated JOURNAL.md and added BOM.csv
    [BOM.csv]
2026-09-04 Moved tesseract.step into production/cad
    [tesseract.step]
